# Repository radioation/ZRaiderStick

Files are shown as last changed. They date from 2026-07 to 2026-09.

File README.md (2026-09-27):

**_IMPORTANT_**: This is still a work in progress. 

# Z Raider Stick
Z Raider - Analog Joystick for Atari 800/XL/XE Computers

Just a nigh-useless analog joystick project for Atari 8-bit computers. It's meant to 
work with my [port](https://github.com/radioation/StarRaidersMods) of the Atari 5200 
Star Raiders analog controls to the 8-bit version. 

Z Raider may work with other Atari consoles but I've not tested this. I've done
a little work with the C64, but it is nowhere near working. The current arduino
code will absolutely _NOT_ work with the C64.

My work is largely based on:
* Jeff Piepmeier's [Atari POKEY Actuation with Arduino](https://jeffpiepmeier.blogspot.com/2020/02/atari-pokey-actuation-with-arduino.html) blog post. My initial tests followed this pretty closesly. He doesn't state which diode he used. So I tried a few that I had on hand and the 1N4001 worked pretty well. Unfortunately, I was having a hard time getting stable values for two axis. A single axis using delays worked well. Adding a second axis introduced jitter. Most likely due to the way I was tracking the pulse delays.
* Danjovic's [Stingray](https://github.com/Danjovic/Stingray). This is Nintendo Classic controller adapter with keypad emulation for the Atari 5200. This project handled the pulse delays in using the Arduino UNO's TIMER2 interrupt to approximate delays for each horizontal line. Using this technique gives much better results than my use of total delay time checked by loop().

# Circuit
**_IMPORTANT_: Any circuits in this project are experimental. I am not a practicing electrical engineer. The circuit diagrams I put (will put) here are what I've tested on my Ataris. The circuits work for me, but I'm _not_ an expert at hardware design. It's possible that I'm doing something incorrectly that may damage the computer. USE THIS PROJECT AT YOUR OWN RISK**

* Arduino UNO R3 or Nano V3. I've tested on Elegoo clones.
* D1, D2 - 1N4001 Diode
* D3 - 1N5817 Schottky Diode
* R1 - 100 Ohm
* R2,R3 - 330 Ohm
* R4 - 2.7 kOhm ( I used 2.2k + 560 ~= 2.76kOhm. The main thing is to get a voltage divider in this range for the comparator )
* R5 - 10 kOhm
* C1,C2 - 100 nF
* S1B, S1C - 10 kOhm ( basic thumbstick, I'm currently looking at RKJXV1224005 thumbsticks in KiCAD )
* F1 - Polyfuse 100mA (Optional. Can use 0 Ohm)
* 6 push button switches

## Atari 800/XL/XE Schematic:
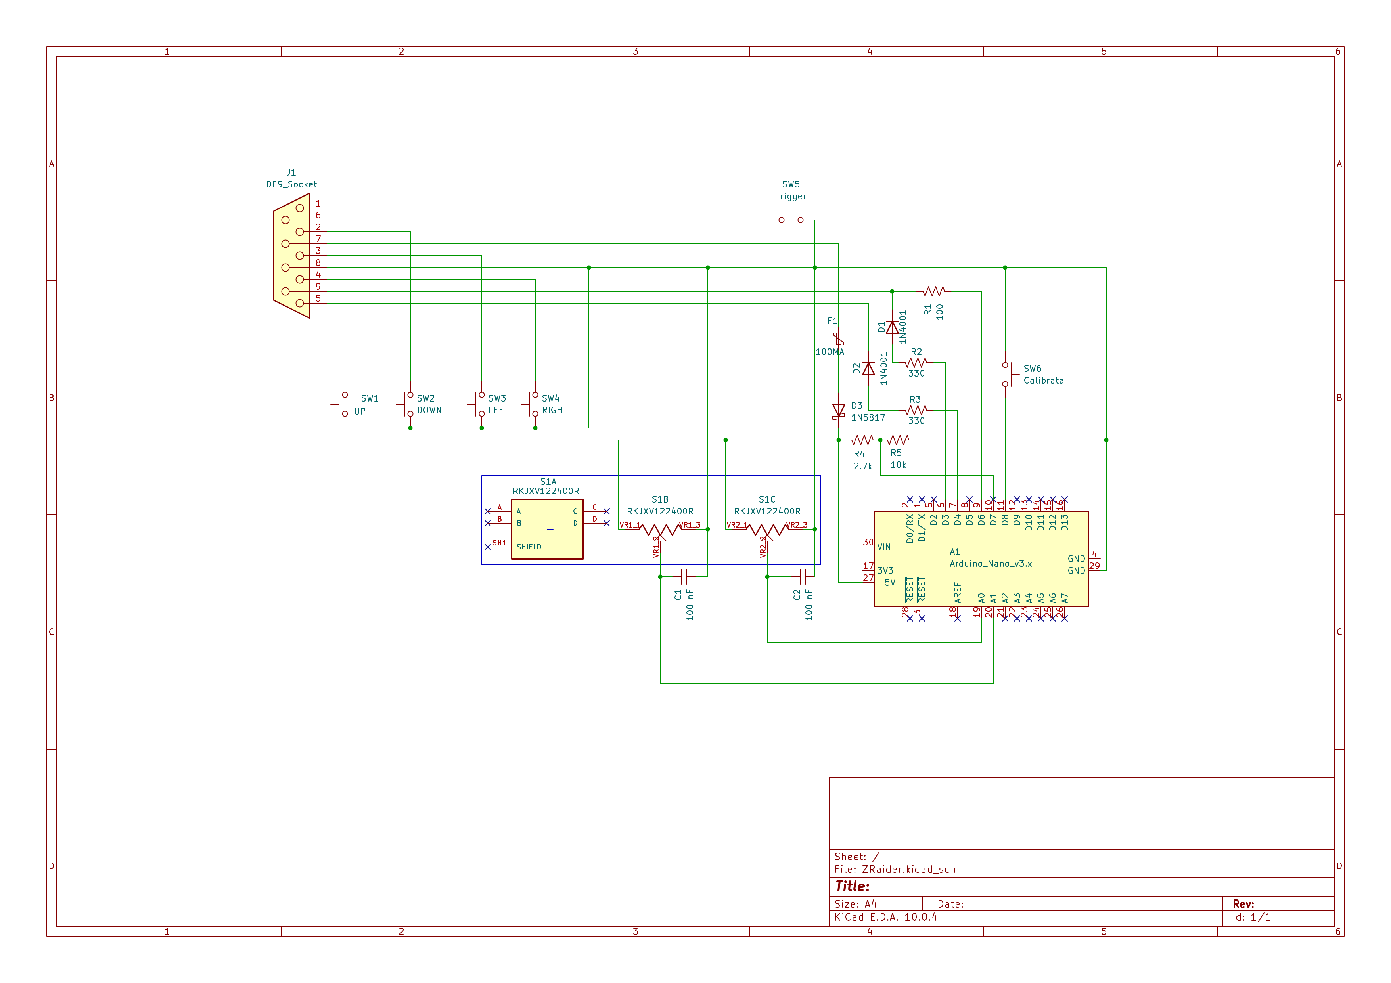
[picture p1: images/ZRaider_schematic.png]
ZRaider schematic


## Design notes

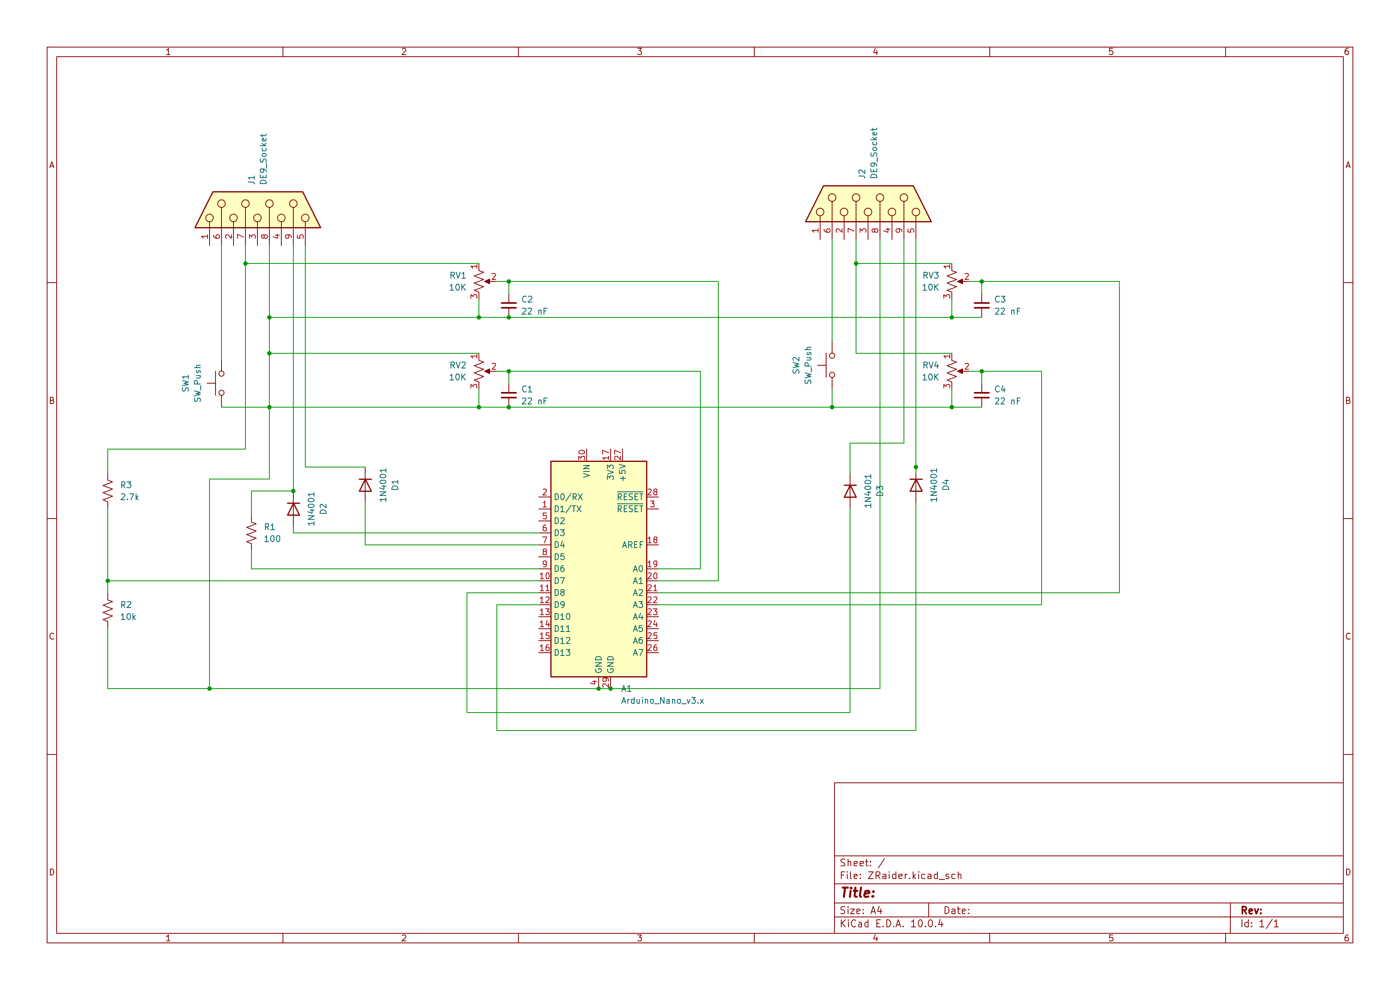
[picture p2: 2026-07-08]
images/Viper_schematic.png

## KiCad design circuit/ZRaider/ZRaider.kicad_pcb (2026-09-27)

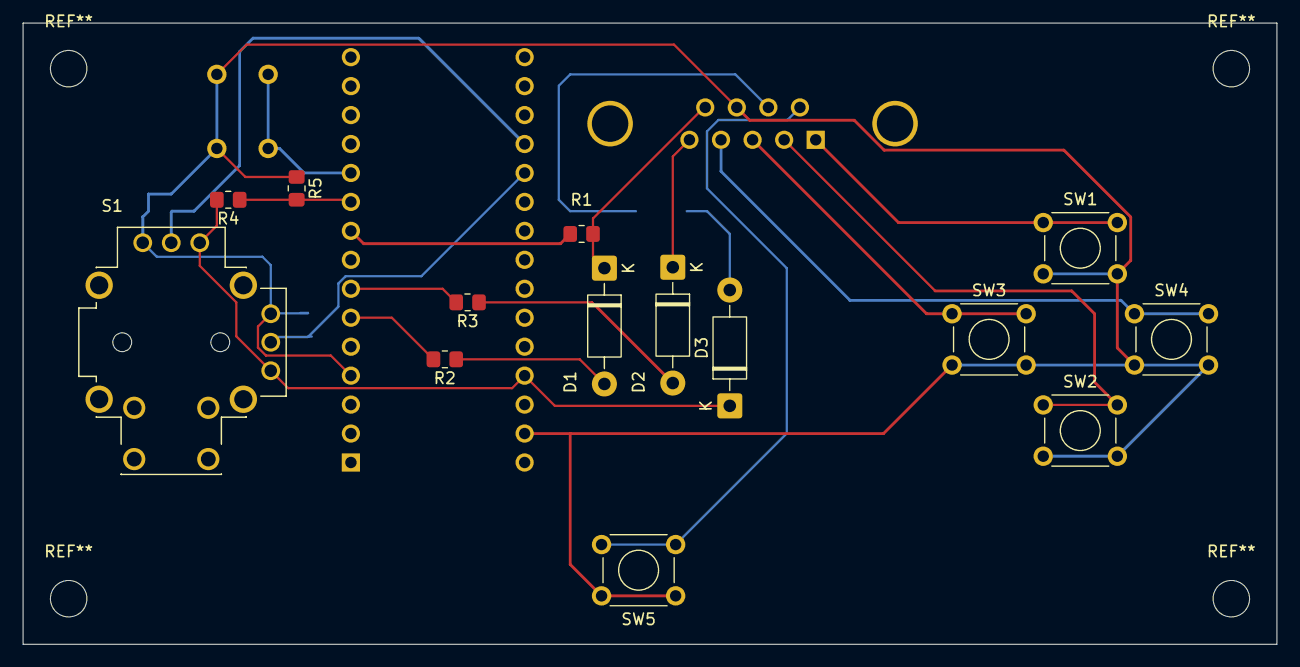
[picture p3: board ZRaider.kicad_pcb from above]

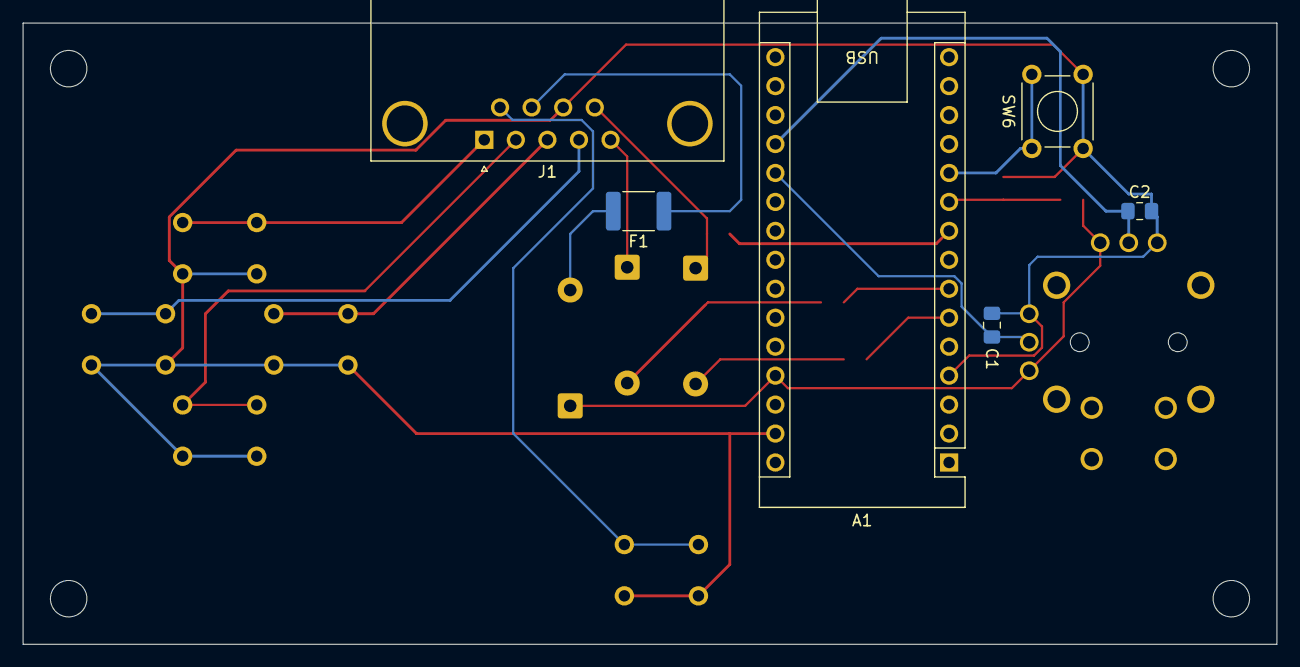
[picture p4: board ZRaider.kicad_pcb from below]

Board: 2 copper layers, 110.0 x 54.5 mm, 20 parts (6 on the bottom side), 19 nets.

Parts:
A1: Arduino_Nano_v3.x; Arduino_Nano
C1, C2: 100 nF; C_0805_2012Metric_Pad1.18x1.45mm_HandSolder
D1, D2: 1N4001; D_DO-41_SOD81_P10.16mm_Horizontal
D3: 1N5817; D_DO-41_SOD81_P10.16mm_Horizontal
F1: 100MA; Fuse_1812_4532Metric_Pad1.30x3.40mm_HandSolder
J1: DE9_Socket; DSUB-9_Socket_Horizontal_P2.77x2.84mm_EdgePinOffset9.90mm_H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
R1: 100; R_0805_2012Metric_Pad1.20x1.40mm_HandSolder
R2, R3: 330; R_0805_2012Metric_Pad1.20x1.40mm_HandSolder
R4: 2.7k; R_0805_2012Metric_Pad1.20x1.40mm_HandSolder
R5: 10k; R_0805_2012Metric_Pad1.20x1.40mm_HandSolder
S1: RKJXV122400R; SW_RKJXV122400R
SW1: UP; SW_TH_Tactile_Omron_B3F-100x
SW2: DOWN; SW_TH_Tactile_Omron_B3F-100x
SW3: LEFT; SW_TH_Tactile_Omron_B3F-100x
SW4: RIGHT; SW_TH_Tactile_Omron_B3F-100x
SW5: Trigger; SW_TH_Tactile_Omron_B3F-100x
SW6: Calibrate; SW_TH_Tactile_Omron_B3F-100x

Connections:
unnamed: A1.27 (+5V), D3.1 (K), R4.2, S1.VR1_1, S1.VR2_1
unnamed: A1.19 (A0), C2.1, S1.VR2_2
unnamed: A1.20 (A1), C1.2, S1.VR1_2
unnamed: A1.6 (D3), R2.2
unnamed: A1.7 (D4), R3.2
unnamed: A1.9 (D6), R1.2
unnamed: A1.11 (D8), SW6.1
unnamed: A1.4 (GND), A1.29 (GND), C1.1, C2.2, J1.8, R5.1, S1.VR1_3, S1.VR2_3, SW1.2, SW2.2, SW3.2, SW4.2, SW5.1, SW6.2
unnamed: D1.2 (A), R2.1
unnamed: D1.1 (K), J1.9, R1.1
unnamed: D2.2 (A), R3.1
unnamed: D2.1 (K), J1.5
unnamed: D3.2 (A), F1.2
unnamed: F1.1, J1.7
unnamed: J1.1, SW1.1
unnamed: J1.2, SW2.1
unnamed: J1.3, SW3.1
unnamed: J1.4, SW4.1
unnamed: J1.6, SW5.2

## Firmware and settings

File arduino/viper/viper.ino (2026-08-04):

#include <avr/io.h>
#include <avr/interrupt.h>
#include <util/atomic.h>
#include <EEPROM.h>

//#define DEBUG 1

#ifdef DEBUG
  #define DEBUG_BEGIN(speed) Serial.begin(speed)
  #define DEBUG_PRINT(x)     Serial.print(x)
  #define DEBUG_PRINTF(format, ...) { \
    char _dbgBuf[64]; \
    snprintf(_dbgBuf, sizeof(_dbgBuf), format, ##__VA_ARGS__); \
    Serial.println(_dbgBuf); \
  }
  #define DEBUG_PRINTLN(x)     Serial.println(x)
#else
  #define DEBUG_BEGIN(speed)
  #define DEBUG_PRINT(x)
  #define DEBUG_PRINTF(format, ...)
  #define DEBUG_PRINTLN(x)
#endif

void (*runLoop)();  

const uint8_t potX1pin = 3;
const uint8_t potY1pin = 4;

const uint8_t potX2pin = 2;
const uint8_t potY2pin = 5;
const uint8_t calibratePin = 8;


const uint8_t thumb1Xpin = A0;
const uint8_t thumb1Ypin = A1;
const uint8_t thumb2Xpin = A2;
const uint8_t thumb2Ypin = A3;


// Struct to store the min/max/middle values found in calibration.
struct CalibrationData {
    uint16_t min1X;
    uint16_t max1X;
    uint16_t mid1X;
    uint16_t min1Y;
    uint16_t max1Y;
    uint16_t mid1Y;

    uint16_t min2X;
    uint16_t max2X;
    uint16_t mid2X;
    uint16_t min2Y;
    uint16_t max2Y;
    uint16_t mid2Y;
};
CalibrationData cal;

#define CALIBRATION_DURATION_MS 10000
#define CAL_BUTTON_LOCKOUT_MS 1000
#define MID_SAMPLE_COUNT 10
unsigned long lockoutStart = 0;
unsigned long calStart = 0;
#define CAL_WRITTEN_FLAG_ADDR 32
const uint8_t WRITTEN_FLAG_VAL = 0xAB;

void saveCalibration() {
    // *IMPORTANT* EEPROM has limited writes, **don't** call repeatedly in a fast loop
    EEPROM.put(0, cal);
    EEPROM.write( CAL_WRITTEN_FLAG_ADDR, WRITTEN_FLAG_VAL);
}

void loadCalibration() {
    EEPROM.get(0, cal);
}


// check for hline getting stuck 
unsigned int hlineStuckCounter = 0; 
const unsigned int HLINE_STUCK_LIMIT = 5;  // just a guess

// Early observation with single axis: Range seems to be 0 to 222 but I see 1-225 in PADDLE() reads. 
// * I did see some strange behavior with 2-axis with values above 210 on my XL and maybe at 0 or 1.  
//   A stable range seems to be 6-210 on my 800XL, this may need to change as I test more units.
//   
// Adding a short delay (rouglhly 31 from observations) as we're not using Stingray's 10k resistor
// and a rising edge to detect delay start
#define PULSE_DELAY 31
#define MIN_RANGE   6
#define MAX_RANGE   210
#define FRAME_END   257


// Use current/next values to updating x/y in 
// the 115 + PULSE_DELAY default is used to check signal stability *without* analogreads.
static volatile uint16_t currPot1X = 115 + PULSE_DELAY;
static volatile uint16_t currPot1Y = 115 + PULSE_DELAY;
static volatile uint16_t nextPot1X = 115 + PULSE_DELAY;
static volatile uint16_t nextPot1Y = 115 + PULSE_DELAY;

static volatile uint16_t currPot2X = 115 + PULSE_DELAY;
static volatile uint16_t currPot2Y = 115 + PULSE_DELAY;
static volatile uint16_t nextPot2X = 115 + PULSE_DELAY;
static volatile uint16_t nextPot2Y = 115 + PULSE_DELAY;

static volatile uint16_t hline = 0;




// Timer 2 interrupt occurs at ~64us
ISR(TIMER2_COMPA_vect)
{
    if( hline < FRAME_END ) {  

        if (hline == currPot1Y) {
            // turn up y axis
            PORTD |= (1 << PD4);
        }

        if (hline == currPot1X) {
            // turn up x axis
            PORTD |= (1 << PD3);
        }

        if (hline == currPot2Y) {
            // turn up y axis
            PORTD |= (1 << PD5);
        }

        if (hline == currPot2X) {
            // turn up x axis
            PORTD |= (1 << PD2);
        }
        ++hline;

    } else if (hline == FRAME_END) {
        // clear them
        PORTD &= ~((1 << PD3) | (1 << PD4) | (1 << PD2) | (1 << PD5));

        ACSR |= (1 << ACI);   // clear any pending interrupt bit
        ACSR |= (1 << ACIE);  // reactivate analog comparator

        // check comparator output bit if it's low
        if( !( ACSR & (1 << ACO))) {
            // line is already low, reset hline
            ACSR &= ~(1 << ACIE);
            hline = 0;    
        }
        ++hline;
    }


}

// Analog comparator, triggers when detect that pokey released POT inputs to charge
ISR(ANALOG_COMP_vect)
{
    // Keep output pins low while POKEY is discharging the POT lines.
    PORTD &= ~((1 << PD3) | (1 << PD4) | (1 << PD2) | (1 << PD5));

    // update the current readings
    currPot1X = nextPot1X;
    currPot1Y = nextPot1Y;
    currPot2X = nextPot2X;
    currPot2Y = nextPot2Y;

    hline = 0;

    // resetting timer (seemes unnecessary)
    ACSR &= ~(1 << ACIE); // disable comparator
}

void restartComparator() { 
    ACSR &= ~(1 << ACIE); // disable comparator

    delayMicroseconds(50); 
    hline= 0;
    ACSR |= (1 << ACI);   // clear any pending interrupt bit
    ACSR |= (1 << ACIE);  // reactivate analog comparator
}


void setup()
{
    DEBUG_BEGIN(9600);

    pinMode(potX1pin, OUTPUT);
    pinMode(potY1pin, OUTPUT);
    pinMode(potX2pin, OUTPUT);
    pinMode(potY2pin, OUTPUT);

    digitalWrite(potX1pin, LOW);
    digitalWrite(potY1pin, LOW);
    digitalWrite(potX2pin, LOW);
    digitalWrite(potY2pin, LOW);

    // setup analog comparator as input
    pinMode(6, INPUT);
    pinMode(7, INPUT);

    // switch
    pinMode( calibratePin, INPUT_PULLUP);


    // Setup Timer2
    TCCR2A = (0 << WGM20) // WGM[2..0] = 010 CTC mode, counts up overflow on OCR2A
        | (1 << WGM21); //
    TCCR2B = (0 << WGM22) //
        | (0 << CS20) // CS[2..0] = 010 Prescaler clock/8
        | (1 << CS21) //
        | (0 << CS22); //
    OCR2A = 127;          // reload value for 15748Hz (63.5us)

    TIMSK2 = (0 << OCIE2B) //  Enable interrupt on match
        | (1 << OCIE2A) //
        | (0 << TOIE2); //


    // Setup Analog Comparator
    ADCSRB = 0;             // (Disable) ACME: Analog Comparator Multiplexer Enable
    ACSR = (1 << ACI)     // (Clear) Analog Comparator Interrupt Flag
        | (1 << ACIE)    // Analog Comparator Interrupt Enable
        | (1 << ACIS1);  // Unlike Stingray/5200, I trigger on FALLING edge (when POKEY clamps to 0V)

    sei();

    if( EEPROM.read( CAL_WRITTEN_FLAG_ADDR) == WRITTEN_FLAG_VAL ) {
        loadCalibration();

    } else {
        // assume whole range.
        cal.max1X = 1023;
        cal.min1X = 0;
        cal.mid1X = 511;
        cal.max1Y = 1023;
        cal.min1Y = 0;
        cal.mid1Y = 511;
        cal.max2X = 1023;
        cal.min2X = 0;
        cal.mid2X = 511;
        cal.max2Y = 1023;
        cal.min2Y = 0;
        cal.mid2Y = 511;
    }

    runLoop = mainLoop;
}

bool buttonPressed() {
    if (millis() < CAL_BUTTON_LOCKOUT_MS  + lockoutStart) return false;   // ignore during lockout
    static bool lastState = HIGH;
    bool state = digitalRead(calibratePin);
    bool pressed = (lastState == HIGH && state == LOW);  // falling edge
    lastState = state;
    if (pressed) lockoutStart = millis();
    return pressed;
}

void mainLoop()
{

    // Read modern thumb1sticks (0 to 1023)
    uint16_t raw1X = analogRead(thumb1Xpin);
    uint16_t raw1Y = 1023 - analogRead(thumb1Ypin);
    uint16_t raw2X = analogRead(thumb2Xpin);
    uint16_t raw2Y = 1023 - analogRead(thumb2Ypin);

    if( raw1X < cal.min1X ) raw1X = cal.min1X;
    if( raw1X > cal.max1X ) raw1X = cal.max1X;
    if( raw1Y < cal.min1Y ) raw1Y = cal.min1Y;
    if( raw1Y > cal.max1Y ) raw1Y = cal.max1Y;

    if( raw2X < cal.min2X ) raw2X = cal.min2X;
    if( raw2X > cal.max2X ) raw2X = cal.max2X;
    if( raw2Y < cal.min2Y ) raw2Y = cal.min2Y;
    if( raw2Y > cal.max2Y ) raw2Y = cal.max2Y;

    DEBUG_PRINTF("ST1 X: [%d] Min:%d Max:%d ST1 Y: [%d] Min:%d Max:%d ST2 X: [%d] Min:%d Max:%d ST2 Y: [%d] Min:%d Max:%d", raw1X, min1X, max1X, raw1Y, min1Y, max1Y, raw2X, min2X, max2X, raw2Y, min2Y, max2Y);


    // map  pot ranges  to usable range  TODO: Consider a non-linear mapping for this.
    const uint16_t mapped1X = MIN_RANGE +   (((uint32_t)(raw1X - cal.min1X) * (MAX_RANGE - MIN_RANGE) + (cal.mid1X-cal.min1X)) / (cal.max1X-cal.min1X)) +  PULSE_DELAY;
    const uint16_t mapped1Y = MIN_RANGE + (((uint32_t)(raw1Y - cal.min1Y)* (MAX_RANGE - MIN_RANGE) + (cal.mid1Y-cal.min1Y)) / (cal.max1Y-cal.min1Y)) + PULSE_DELAY;
    const uint16_t mapped2X = MIN_RANGE +   (((uint32_t)(raw2X - cal.min2X) * (MAX_RANGE - MIN_RANGE) + (cal.mid2X-cal.min2X)) / (cal.max2X-cal.min2X)) +  PULSE_DELAY;
    const uint16_t mapped2Y = MIN_RANGE + (((uint32_t)(raw2Y - cal.min2Y)* (MAX_RANGE - MIN_RANGE) + (cal.mid2Y-cal.min2Y)) / (cal.max2Y-cal.min2Y)) + PULSE_DELAY;
 
    // save for next interrupt
    ATOMIC_BLOCK(ATOMIC_RESTORESTATE) {
        nextPot1X = mapped1X;
        nextPot1Y = mapped1Y;
        nextPot2X = mapped2X;
        nextPot2Y = mapped2Y;
    }

    //are we stuck?
    if (hline >= 258) {
        hlineStuckCounter++;
        if( hlineStuckCounter > HLINE_STUCK_LIMIT ) {
            restartComparator();
            hlineStuckCounter = 0;
        }
    } else {
        hlineStuckCounter = 0; 
    }

    if( buttonPressed()){
        startCalibration();
    }
    delay(3);
}

void startCalibration() {

    DEBUG_PRINT("START CAL\n");

    // get a few readings for center.
    uint32_t sum1X = 0;
    uint32_t sum1Y = 0;
    uint32_t sum2X = 0;
    uint32_t sum2Y = 0;
    for( int i=0; i <MID_SAMPLE_COUNT ; i++ ) {
        sum1X +=  analogRead(thumb1Xpin);
        sum1Y += 1023 - analogRead(thumb1Ypin);
        sum2X +=  analogRead(thumb2Xpin);
        sum2Y += 1023 - analogRead(thumb2Ypin);
        delay(10);
    }
    cal.mid1X = sum1X / MID_SAMPLE_COUNT;
    cal.mid1Y = sum1Y / MID_SAMPLE_COUNT;
    cal.min1X = 1023; cal.max1X = 0;
    cal.min1Y = 1023; cal.max1Y = 0; 

    cal.mid2X = sum2X / MID_SAMPLE_COUNT;
    cal.mid2Y = sum2Y / MID_SAMPLE_COUNT;
    cal.min2X = 1023; cal.max2X = 0;
    cal.min2Y = 1023; cal.max2Y = 0; 
    calStart = millis();
    runLoop = calibrationLoop;

}

void calibrationLoop() {
    const uint16_t raw1X = analogRead(thumb1Xpin);
    const uint16_t raw1Y = 1023 - analogRead(thumb1Ypin);
    const uint16_t raw2X = analogRead(thumb2Xpin);
    const uint16_t raw2Y = 1023 - analogRead(thumb2Ypin);

    //  get min/max vals
    if (raw1X < cal.min1X) cal.min1X = raw1X;  
    if (raw1X > cal.max1X) cal.max1X = raw1X;
    if (raw1Y < cal.min1Y) cal.min1Y = raw1Y;  
    if (raw1Y > cal.max1Y) cal.max1Y = raw1Y;

    if (raw2X < cal.min2X) cal.min2X = raw2X;  
    if (raw2X > cal.max2X) cal.max2X = raw2X;
    if (raw2Y < cal.min2Y) cal.min2Y = raw2Y;  
    if (raw2Y > cal.max2Y) cal.max2Y = raw2Y;


    bool timedOut = ( millis() >  calStart +CALIBRATION_DURATION_MS );
    bool userQuit = buttonPressed();

    if( timedOut || userQuit ) {
        runLoop = mainLoop; // exit calibration loop by switching to mainLoop
        saveCalibration(); // eeprom has limited life only call when exiting calibration

        DEBUG_PRINTF("1 MID X: [%d] Min: %d Max: %d MID Y: [%d] Min: %d Max: %d", cal.mid1X, cal.min1X, cal.max1X,   cal.mid1Y, cal.min1Y, cal.max1Y);
        DEBUG_PRINTF("2 MID X: [%d] Min: %d Max: %d MID Y: [%d] Min: %d Max: %d", cal.mid2X, cal.min2X, cal.max2X,   cal.mid2Y, cal.min2Y, cal.max2Y);
    }
}

void loop() {
    runLoop();
}

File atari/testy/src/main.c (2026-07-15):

#include <atari.h>
#include <string.h>
#include <stdint.h>
#include <peekpoke.h>
#include <conio.h>

#include "pmg.h"

#define PADDL0_ADDR 624
#define PADDL1_ADDR 625
#define PADDL2_ADDR 626
#define PADDL3_ADDR 627
#define CH_ADDR     764

#define MAX_PADDLE  180

#define PM_X_MIN    48
#define PM_X_MAX    208

#define PM_Y_MIN    32
#define PM_Y_MAX    223

static uint8_t *player0;
static uint8_t *player1;


static uint8_t clamp_paddle(uint8_t v)
{
    return (v > MAX_PADDLE) ? MAX_PADDLE : v;
}

static uint8_t map_paddle_to_hpos(uint8_t p)
{
    p = clamp_paddle(p);

    return (uint8_t)(PM_X_MIN + (((uint16_t)p * (PM_X_MAX - PM_X_MIN)) / MAX_PADDLE));
}

static uint8_t map_paddle_to_y(uint8_t p)
{
      uint16_t v;

    p = clamp_paddle(p);

    v = PM_Y_MAX - (((uint16_t)p * (PM_Y_MAX - PM_Y_MIN)) / MAX_PADDLE);

    return (uint8_t)v;
}

static void erase_dot(uint8_t* player, uint8_t y)
{
    player[y - 2] = 0x00;
    player[y - 1] = 0x00;
    player[y]     = 0x00;
    player[y + 1] = 0x00;
    player[y + 2] = 0x00;
}

static void draw_dot(uint8_t* player, uint8_t y)
{
    player[y - 2] = 0x18;
    player[y - 1] = 0x18;
    player[y]     = 0x7E;
    player[y + 1] = 0x18;
    player[y + 2] = 0x18;
}

int main(void)
{
    uint16_t p = (uint16_t)pmgMem;

    uint8_t p0x;
    uint8_t p0y;
    uint8_t x0;
    uint8_t y0;
    uint8_t old_y0;
    uint8_t p1x;
    uint8_t p1y;
    uint8_t x1;
    uint8_t y2;
    uint8_t old_y2;

    uint8_t stick0;
    uint8_t stick1;
    clrscr();

    ANTIC.pmbase = p >> 8;
    memset(pmgMem, 0, 2048);

    OS.sdmctl = 62; // single line PM

    GTIA_WRITE.gractl = 0x03;
    GTIA_WRITE.sizep0 = 0x00;

    OS.color1 = 0x0F; // text
    OS.color2 = 0x98; // bg
    OS.color4 = 0x98;
    OS.gprior = 1;
    OS.pcolr0 = 0x42;
    OS.pcolr1 = 0xC2;

    player0 = pmgMem + 1024;// In single-line PM mode, player 0 starts at PM base + 1024.
    player1 = pmgMem + 1280;// player 1 starts at PM base + 1280.


    POKE(CH_ADDR, 255);

    gotoxy(0,0);
    cprintf("A8 Raider Stick Test");

    while (1) {
      // paddles
        p0x = PEEK(PADDL0_ADDR);
        p0y = PEEK(PADDL1_ADDR);
        p1x = PEEK(PADDL2_ADDR);
        p1y = PEEK(PADDL3_ADDR);

        x0 = map_paddle_to_hpos(p0x);
        y0 = map_paddle_to_y(p0y);
        x1 = map_paddle_to_hpos(p1x);
        y2 = map_paddle_to_y(p1y);


        erase_dot(player0, old_y0);
        draw_dot(player0, y0);
        old_y0 = y0;

        erase_dot(player1, old_y2);
        draw_dot(player1, y2);
        old_y2 = y2;

        GTIA_WRITE.hposp0 = x0;
        GTIA_WRITE.hposp1 = x1;

        gotoxy( 0, 20);
        cprintf( "X1:%3u Y1:%3u", x0, y0);
        gotoxy( 26, 20);
        cprintf( "X2:%3u Y2:%3u", x1, y2);

        // sticks
        stick0 = PEEK(632);
        gotoxy( 9,10 );
        cputc('U'+ ( ~stick0 & 0x01 ?  128 : 0));
        gotoxy( 9,14 );                      
        cputc('D'+ ( ~stick0 & 0x02 ?  128 : 0));
        gotoxy( 7,12 );                      
        cputc('L'+ ( ~stick0 & 0x04 ?  128 : 0));
        gotoxy( 11,12 );                     
        cputc('R'+ ( ~stick0 & 0x08 ?  128 : 0));
        gotoxy( 13,10 );
        cputc('F'+ (PEEK(644) ? 0 : 128));
        // sticks
        stick1 = PEEK(633);
        gotoxy( 29,10 );
        cputc('U'+ ( ~stick1 & 0x01 ?  128 : 0));
        gotoxy( 29,14 );
        cputc('D'+ ( ~stick1 & 0x02 ?  128 : 0));
        gotoxy( 27,12 );
        cputc('L'+ ( ~stick1 & 0x04 ?  128 : 0));
        gotoxy( 31,12 );
        cputc('R'+ ( ~stick1 & 0x08 ?  128 : 0));
        gotoxy( 33,10 );
        cputc('F'+ (PEEK(645) ? 0 : 128));
    }

    // nevah!
    return 0;
}

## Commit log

2026-07-01 adding test code
    [atari-xex.cfg]
2026-07-01 adding parts of circuit
2026-07-08 Revise component details and circuit connections in README
    Updated component descriptions and clarified resistor values. Removed outdated TODO and detailed circuit connections.
2026-07-10 Revise Arduino compatibility details in README
    Updated the hardware compatibility information and clarified the testing details for Arduino boards.
2026-07-12 adding debug printing
2026-07-19 working on calibration
2026-07-22 Revise README for clarity and additional components
    Updated README to clarify project status and circuit details.
2026-07-26 bug fix: keep raw values within calibration range.
    [raider.ino]
2026-07-26 re-add ground to pot
2026-07-26 adding kicad files
    [ZRaider.kicad_pcb, ZRaider.kicad_sch]
2026-07-26 adding last remaining connections
    [ZRaider.kicad_pcb, ZRaider.kicad_sch]
2026-07-26 Revise component values and add optional parts
    Updated resistor and capacitor values, added optional components.
2026-07-27 moving arduino file to subfolder
2026-08-01 updating layout to accomodate J1 size (actual) vs library
    [ZRaider.kicad_pcb, ZRaider.kicad_sch]
2026-08-01 adding mounting holes
    [ZRaider.kicad_pcb]
2026-08-04 tweaking board size based on DB9's I've got onhand
    [ZRaider.kicad_pcb]
2026-09-27 updating fuse footprint
    [ZRaider.kicad_pcb, ZRaider.kicad_sch]
2026-09-27 updating fuse
2026-10-21 starting twinstick schematic
2026-10-21 adding resistors to 2nd thumbstick output
2026-10-21 fixing 300 resistors. updating labels
2026-10-21 Fixing resistor val.
2026-10-21 working on PCB layout
2026-10-21 working on viper PCB layout
